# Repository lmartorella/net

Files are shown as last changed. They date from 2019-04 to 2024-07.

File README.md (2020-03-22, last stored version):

# Home

This is a hobbist/educational fulls stack project about Internet of Things (IoT) for DIY enthusiasts. It starts from scratch, using bare microcontrollers (MCU), network, and PC software without any relevant dependency.

The idea is about implementing a lost-cost open-source, open-hardware wired platform for general purpose automation control (for example domotic projects, security, garden automation, etc...). It is designed to connect a whole home and its surroundings.

The core of the project is a tiny MCU board that can embedded in any hardware, even a normal wall switch.

Node-to-node communication happens via common 4-wire or 6-wire low-voltage cables, like KNX, CAN-bus or other commercial systems, using industrial-grade [RS-485](https://en.wikipedia.org/wiki/RS-485) specifications for great scalability. Node-to-master communication is through IP (e.g. ethernet, wifi, etc...) for improved scalability. This allow wireless nodes to be implemented as well. 

What this project is aimed to:
- connect any type of sensor 
- integrate devices that can be interfaced via a MCU
- log data
- implement custom logic to automate tasks
- have a web interface for remote control

The bus structure allow extension with other open standards for IoT.

# The network

The network topology uses two mediums: a custom wired low-voltage bus to allow simple MCUs to be used, and a higher LAN/IP level to aggregate wired sections and server connection.

The wired design is similar to the [KNX](https://en.wikipedia.org/wiki/KNX_(standard)) open standard. However, instead of using proprietary electrical bus drivers, it relies on the broadly available [RS-485](https://en.wikipedia.org/wiki/RS-485) standard (for example, a [Maxim MAX485 IC](https://www.maximintegrated.com/en/products/interface/transceivers/MAX485.html) can be used as a driver).

An industrial-level RS-485 bus can range up to 32 nodes on the same wire and span hundreds of meters, even on electrically noisy environments. See [Maxim Integrated AN](https://www.maximintegrated.com/en/app-notes/index.mvp/id/3884).

Frames are byte-oriented, allowing a common bi-directional [UART](https://en.wikipedia.org/wiki/Universal_asynchronous_receiver-transmitter) to be used. This simplifies the selection of the hardware, since no bit-level CAN-bus or MODBUS logic is required. 

Each wired section needs to contain a *master* node, that allows IP connection to the server through Wi-Fi or Ethernet cables (it needs both UDP and TCP).

The custom protocol built on top is designed to offer features to ease the network installation:
- Auto-discovery for all connected nodes
- Zero-configuration: allow dynamic allocation of nodes via push-button and a PC application
- Fail-over due to bus failures, IP connection failures or node failures.

The byte-level message-based protocol is then shared between wired sections and to increase simplicity and issue analysis.

More details [in this page](doc/protocol.md).

# The microbean (µBean)

The prototyped hardware is a small board (just 30x28mm) built around a cost-effective [Microchip PIC16F1827 MCU](https://www.microchip.com/wwwproducts/en/PIC16F1827), a RS-485 level adapter and a voltage regulator. The board expose almost all MCU lines to the maker, allowing a great amount of free digital and analog I/O pins.

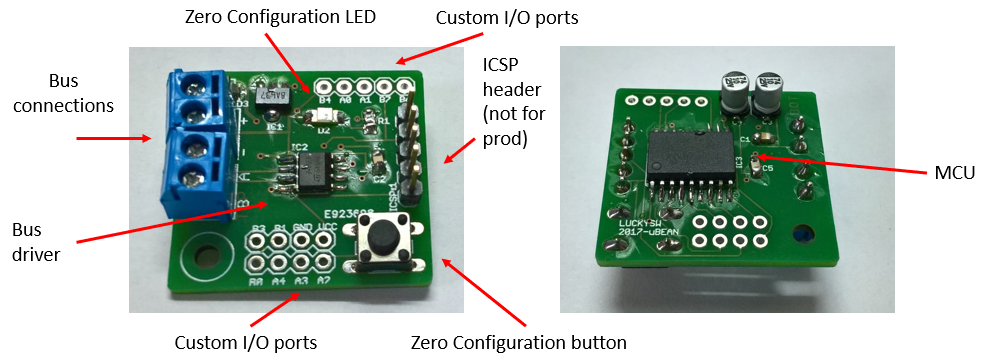
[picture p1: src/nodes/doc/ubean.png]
The microbean


Once the MCU are programmed, the network topology can be easily configured with a PC.

Each physical node exposes one or more applicative drivers, called *sinks*. In this way, a single bean can be programmed to interface more than one device.

More details can be found [here](./src/nodes/doc/microbean.md).

# Some examples

A collection of sample code for beans can be found in the samples folder.

Each sample is documented [here](./samples/beans/README.md).

## Light control

One bean installed in each wall box.
- Common switches will be used as low power digital switch drivers, or push button style
- Touch switches support
- RGB LEDs can be installed in each switch allowing soft tone transitions and night mode
- Power line relays or FET boards in separated junction boxes to control lights
- PWM with zero-cross detection dimmer boards for bulbs that support it
- IR motion/presence sensors support
- Luminance sensors for power saving support

## Intrusion detection and report

- A bean for each IR/motion sensor.
- A bean in junction boxes for window and doors magnetic switch.
- Beans at entrances for RFID or physical keys.
- Real-time notification of unusual activity
- Phone call/SMS/IM alert
- Remote control
- Remote activation/deactivation
- Smartphone control

## Climatization

Beans can be used to interact with existing climatization systems
- Temperature and humidity sensors
- IR emitters for fans and air conditioning units
- Actuator interfacing for motorized window shutters
- Regulation made based on weather forecast services

## Garden irrigation system

- Beans to control electrical valves
- Rain sensors
- Level meter for water tanks
- Relays board for submerged pumps
- Planning made based on weather forecast services

## Power management

- Interfacing with power meters that supports a serial port or a IP protocol.
- Interfacing with solar inverters.
- Wind meters to auto-close awnings.
- Connection with smart meters and devices.

# How to build

The project contains software elements (the .NET server, the node simulators and the control panel UI), hardware (the microbean) and the firmware for these nodes.

It is however possible to run the system with a software-only environment, using the node simulators to have a try.

## The server

The server code is a C# command-line process. It doesn't have any 3rd party dependency other than the .NET Framework, and it could be easily ported to [.NET Core](https://dotnet.microsoft.com/download).

However, currently it requires [Visual Studio](https://visualstudio.microsoft.com/) and [.NET Framework 4.x](https://dotnet.microsoft.com/download).

The project is splitted between the core part and the samples dlls, that are loaded automatically at startup via a plug-in load system, allowing modular architecture.

In addition, a WPF application is generated as a administrative interface (to visualize and set-up the network hierarchy) and to allow simulation of node logic and his sinks.

See [here](src/server/README.md) for more information.

## The master node

A master node is required to translate the IP connection from the server to the wired sections.

Custom hardware can be used there, but the simplest solution is perhaps to use an Arduino or a [Raspberry Pi Zero W](https://www.raspberrypi.org/products/raspberry-pi-zero-w/): something that can drive a bidirectional serial port and that can be connected to the LAN.

In this project you will found two implementations:
- for Raspberry (Raspbian) 
- for Microchip MCU with Ethernet support (e.g. PIC18F87). The [Microchip MPLAB X IDE](https://www.microchip.com/mplab/mplab-x-ide) with [XC8 compiler](https://www.microchip.com/mplab/compilers) is required in this case.

See [here](src/nodes/README.md) for more information.

## The wired node

You will find the schematics and the Microchip firmware to implement a wired node. Different ranges of MCU can be used, since the code and data requirements are quite limited.

The [Microchip MPLAB X IDE](https://www.microchip.com/mplab/mplab-x-ide) with [XC8 compiler](https://www.microchip.com/mplab/compilers) is required to compile the firmware and the samples.

See [here](src/nodes/README.md) for more information.

## The web server

A minimalistic web-server implementation is presented to allow remote access to the applications exposed by the server.

See [here](src/web/README.md) for more information.

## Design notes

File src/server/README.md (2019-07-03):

# The server: core C# projects

These are the projects that need to be built to implement the .NET server.

> The project doesn't have any 3rd party dependency other than the .NET Framework, in order to be ported to [.NET Core](https://dotnet.microsoft.com/download) or other platforms.

It requires [Visual Studio](https://visualstudio.microsoft.com/) (the free Community version is fine) and the [.NET Framework 4.x](https://dotnet.microsoft.com/download) for the administrative UI.

## Home.Common

This is C# library that shares code for the other two applications.

You will find here:
- Small dependency injection code
- Serialization services
- IPC services
- Logging a DB service
- The API to write applications: `IDevice` (the logic abstraction that needs one or more drivers) and `ISink`  (the driver part that communicates with the node over the Home protocol).
- An e-mail notification system.

## Home.Server

This is the command-line server process. It dynamically loads applicative *dlls* at startup (see samples) to integrate all the logic.

Place the sample dlls in the same folder of the main application: they will be recognized via attributes and loaded. 

## Home.Manager.UI

This WPF application can be used to:
- Visualize the network topology
- Initialize nodes
- Configure devices linking them to individual node sinks.
- Spawn simulated nodes on the IP network, for testing.

Like the server, also this application loads applicative dlls at startup. In addition to logic dlls, it allow UI dlls to load simulator and mock code as well.

## Application and samples

See [here](../../samples/server/README.md) for the samples, to build an application that does something.

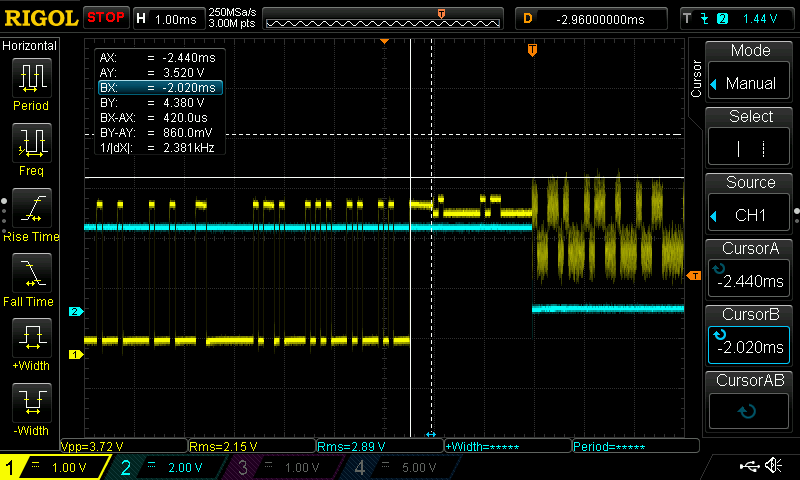
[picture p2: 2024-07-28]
doc/resp.png

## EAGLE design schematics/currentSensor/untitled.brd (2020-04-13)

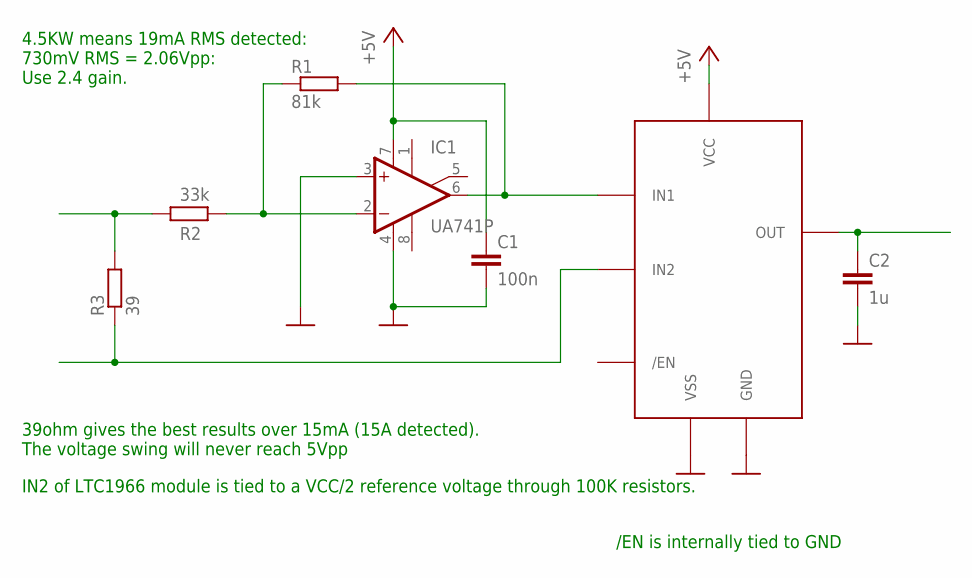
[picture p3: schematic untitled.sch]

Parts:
C1: 100n; C025-025X050
C2: 1u; C025-025X050
IC1: UA741P; DIL08
R1: 81k; 0207/10
R2: 33k; 0207/10
R3: 39; 0207/10
U$1: LTC1966_MODULE

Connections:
+5V: C1.1, IC1.7 (V+), U$1.P$1 (VCC)
GND: C1.2, C2.2, IC1.3 (+IN), IC1.4 (V-), U$1.P$2 (GND), U$1.P$3 (VSS)
unnamed: IC1.2 (-IN), R1.1, R2.2
unnamed: IC1.6 (OUT), R1.2, U$1.P$4 (IN1)
unnamed: R3.1, U$1.P$5 (IN2)
unnamed: R2.1, R3.2
unnamed: C2.1, U$1.P$6 (OUT)

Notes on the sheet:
IN2 of LTC1966 module is tied to a VCC/2 reference voltage through 100K resistors.
39ohm gives the best results over 15mA (15A detected). The voltage swing will never reach 5Vpp
/EN is internally tied to GND
4.5KW means 19mA RMS detected: 730mV RMS = 2.06Vpp: Use 2.4 gain.

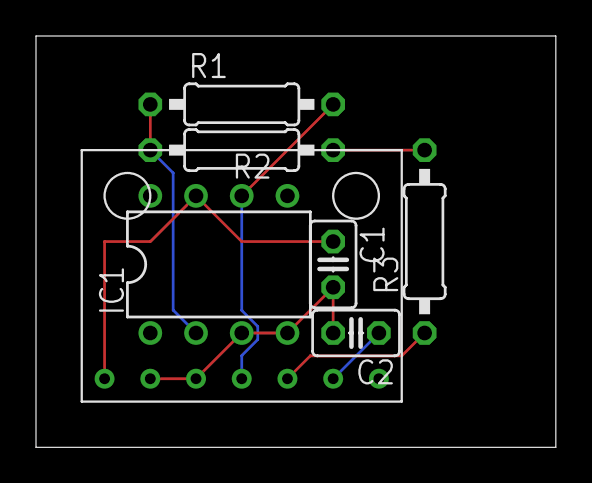
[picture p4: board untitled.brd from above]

Board: 2 copper layers, 28.9 x 22.9 mm, 7 parts (0 on the bottom side), 7 nets.

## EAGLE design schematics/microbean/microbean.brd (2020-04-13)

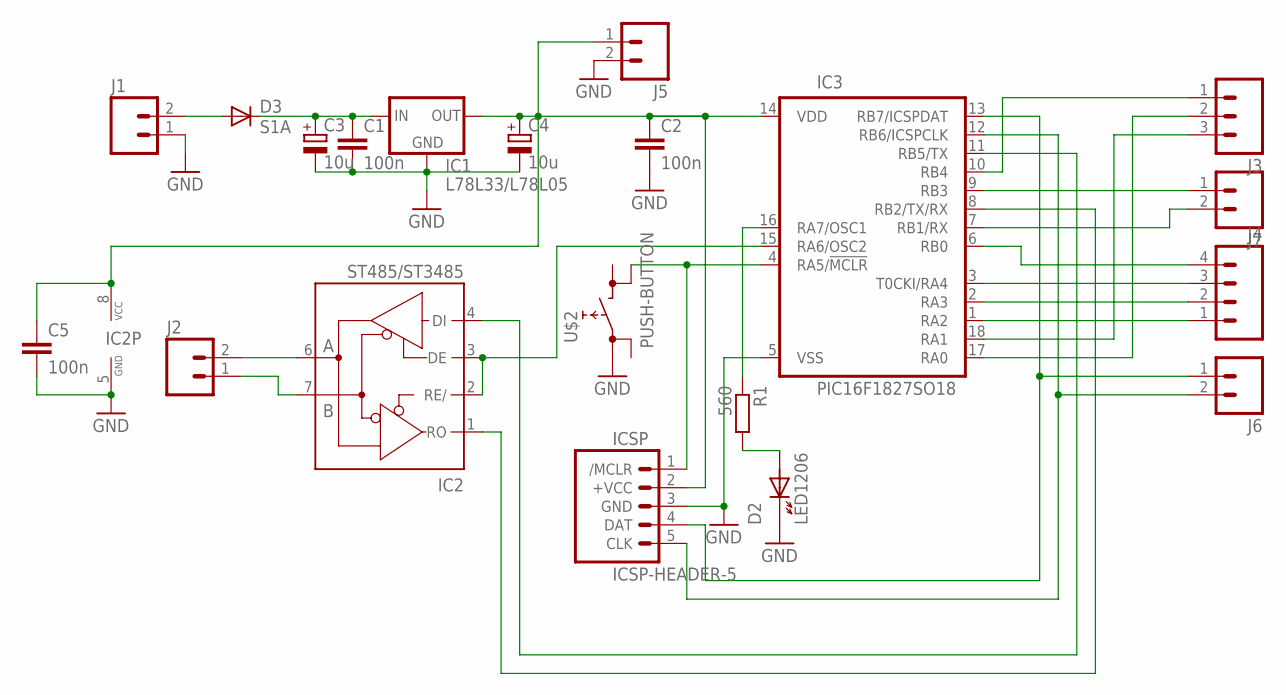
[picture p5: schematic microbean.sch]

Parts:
C1, C2, C5: 100n; C0805
C3, C4: 10u; UD-4X5,8_NICHICON
D2: LED1206; CHIPLED_1206
D3: S1A; SMA
IC1: L78L33/L78L05; SOT89
IC2: ST485/ST3485; SO08
IC3: PIC16F1827SO18; SO18W
ICSP: ICSP-HEADER-5; 1X05
J1, J2: M02-SCREW-3.5MM3.5MM; SCREWTERMINAL-3.5MM-2
J3: M03; 1X03
J4: M04; 1X04
J5, J6, J7: M02; 1X02
R1: 560; R0805
U$2: PUSH-BUTTON; MICRO-SWITCH

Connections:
A: IC2.6 (A), J2.2
B: IC2.7 (B), J2.1
GND: C1.2, C2.2, C3.-, C4.-, C5.2, D2.C (K), IC1.2 (GND), IC1.2@1 (GND), IC2.5 (GND), IC3.5 (VSS), ICSP.3 (GND), J1.1, J5.2, U$2.1 (0)
MCLR: IC3.4 (RA5/!MCLR), ICSP.1 (/MCLR), U$2.4 (1)
unnamed: D3.A, J1.2
unnamed: C1.1, C3.+, D3.C, IC1.3 (IN)
unnamed: D2.A, R1.2
RA0: IC3.17 (RA0), J3.2
RA1: IC3.18 (RA1), J3.3
RA2: IC3.1 (RA2), J4.1
RA3: IC3.2 (RA3), J4.2
RA4: IC3.3 (T0CKI/RA4), J4.3
RA6: IC2.2 (RE/), IC2.3 (DE), IC3.15 (RA6/OSC2)
RA7: IC3.16 (RA7/OSC1), R1.1
RB0: IC3.6 (RB0), J4.4
RB1: IC3.7 (RB1/RX), J7.2
RB2: IC2.1 (RO), IC3.8 (RB2/TX/RX)
RB3: IC3.9 (RB3), J7.1
RB4: IC3.10 (RB4), J3.1
RB5: IC2.4 (DI), IC3.11 (RB5/TX)
RB6: IC3.12 (RB6/ICSPCLK), ICSP.5 (CLK), J6.2
RB7: IC3.13 (RB7/ICSPDAT), ICSP.4 (DAT), J6.1
VCC: C2.1, C4.+, C5.1, IC1.1 (OUT), IC2.8 (VCC), IC3.14 (VDD), ICSP.2 (+VCC), J5.1

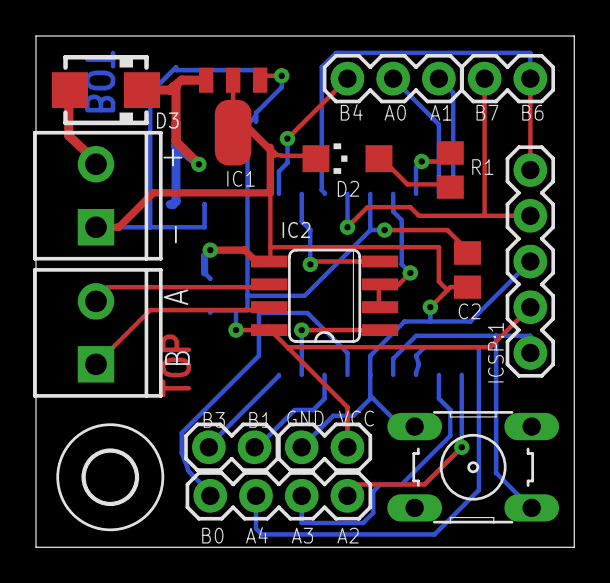
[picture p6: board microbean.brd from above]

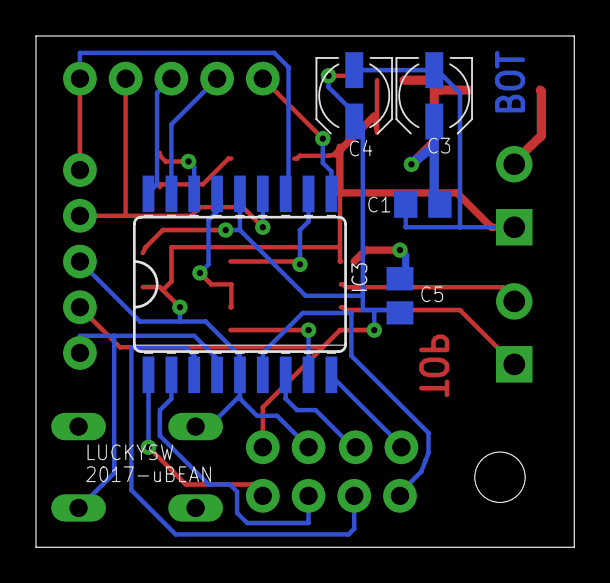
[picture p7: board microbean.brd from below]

Board: 2 copper layers, 29.9 x 28.4 mm, 21 parts (5 on the bottom side), 23 nets.

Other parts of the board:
U$4: 2,8

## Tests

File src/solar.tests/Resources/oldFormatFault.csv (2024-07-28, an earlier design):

TimeStamp | PowerW | TotalEnergyKWh | Mode | EnergyTodayWh | GridCurrentA | PanelCurrentA | GridVoltageV | PanelVoltageV | GridFrequencyHz | Fault
07:52:01 | 10 | 2529 | 0 | 0 | 0.00 | 0.00 | 226.4 | 106.7 | 50.00 | 0
07:52:16 | 20 | 2529 | 2 | 0 | 0.00 | 0.00 | 226.4 | 109.3 | 49.97 | 8192
07:52:31 | 30 | 2529 | 0 | 0 | 0.00 | 0.00 | 226.6 | 117.2 | 49.99 | 0

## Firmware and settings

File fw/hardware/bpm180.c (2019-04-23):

#include "../pch.h"
#include "bpm180.h"
#include "i2c.h"
#include "./appio.h"

// BPM180 I2C module to read barometric data (air pressure)
#ifdef HAS_BPM180

static TICK_TYPE s_lastTime;
#define REG_READ 0xef
#define REG_WRITE 0xee

#define MESSAGE_READ_TEMP 0x2e
#define MESSAGE_READ_PRESS_OSS_0 0x34
#define MESSAGE_READ_PRESS_OSS_1 0x74
#define MESSAGE_READ_PRESS_OSS_2 0xb4
#define MESSAGE_READ_PRESS_OSS_3 0xf4

#define ADDR_CALIB0 0xaa
#define ADDR_CALIB21 0xbf
#define ADDR_DEVICE_ID 0xd0
#define ADDR_MSG_CONTROL 0xf4
#define ADDR_MSB 0xf6
#define ADDR_LSB 0xf7
#define ADDR_XLSB 0xf8

// BPM180 state machine
static enum {
    STATE_IDLE,
    STATE_ASK_ID,
    STATE_RCV_ID,
    STATE_ASK_CALIB_TABLE,
    STATE_RCV_CALIB_TABLE,
    STATE_ASK_TEMP,
    STATE_ASK_TEMP_2,
    STATE_RCV_TEMP,
    STATE_ASK_PRESS,
    STATE_ASK_PRESS_2,
    STATE_RCV_PRESS
} s_state;

static BYTE s_buffer[16];
static int s_counter = 0;

static struct {
    short ac1;
    short ac2;
    short ac3;
    unsigned short ac4;
    unsigned short ac5;
    unsigned short ac6;
    short b1;
    short b2;
    short mb;
    short mc;
    short md;
} s_calibTable;
// Uncompensate temp
static unsigned long s_ut;
// Uncompensate pressure
static unsigned long s_up;

void bpm180_init() {
    s_state = STATE_IDLE;
    i2c_init();
    s_lastTime = TickGet();
}

void bpm180_poll() {
    int oss = 3;
    BOOL i2cIdle = i2c_poll();
    if (!i2cIdle) {
        return; 
    }
    
    switch (s_state) {
        case STATE_IDLE:
            // Start reading?
            if ((TickGet() - s_lastTime) > (TICK_SECOND * 2)) {
                s_buffer[0] = ADDR_DEVICE_ID;
                i2c_sendReceive7(REG_WRITE, 1, s_buffer);
                s_state = STATE_ASK_ID;
            }
            break;
        case STATE_ASK_ID:
            // Start read buffer
            i2c_sendReceive7(REG_READ, 1, s_buffer);
            s_state = STATE_RCV_ID;
            break;
        case STATE_RCV_ID:
            if (s_buffer[0] != 0x55) {
                fatal("B.ID");
            }

            // Ask table
            s_buffer[0] = ADDR_CALIB0;
            i2c_sendReceive7(REG_WRITE, 1, s_buffer);
            s_state = STATE_ASK_CALIB_TABLE;
            break;
            
        case STATE_ASK_CALIB_TABLE:
            // Start read table
            i2c_sendReceive7(REG_READ, 22, (void*)&s_calibTable);
            s_state = STATE_RCV_CALIB_TABLE;
            break;

        case STATE_RCV_CALIB_TABLE:   
            // Change endianness
            for (int i = 0; i < 11; i++) {
                BYTE b1 = ((BYTE*)&s_calibTable)[i * 2];
                ((BYTE*)&s_calibTable)[i * 2] = ((BYTE*)&s_calibTable)[i * 2 + 1];
                ((BYTE*)&s_calibTable)[i * 2 + 1] = b1;
            }
            
            // Ask temp
            s_buffer[0] = ADDR_MSG_CONTROL;
            s_buffer[1] = MESSAGE_READ_TEMP;
            i2c_sendReceive7(REG_WRITE, 2, s_buffer);
            s_state = STATE_ASK_TEMP;
            s_lastTime = TickGet();
            break;
        case STATE_ASK_TEMP:   
            if ((TickGet() - s_lastTime) > (TICKS_PER_MSECOND * 5)) {
                s_buffer[0] = ADDR_MSB;
                i2c_sendReceive7(REG_WRITE, 1, s_buffer);
                s_state = STATE_ASK_TEMP_2;
            }
            break;
        case STATE_ASK_TEMP_2:
            // Read results
            i2c_sendReceive7(REG_READ, 2, s_buffer);
            s_state = STATE_RCV_TEMP;
            break;
        case STATE_RCV_TEMP:
            // invert temp
            s_ut = ((unsigned long)s_buffer[0] << 8) | (unsigned long)s_buffer[1];

            // Ask pressure (min sampling)
            s_buffer[0] = ADDR_MSG_CONTROL;
            s_buffer[1] = MESSAGE_READ_PRESS_OSS_3;
            i2c_sendReceive7(REG_WRITE, 2, s_buffer);
            s_state = STATE_ASK_PRESS;
            s_lastTime = TickGet();
            break;
        case STATE_ASK_PRESS:   
            if ((TickGet() - s_lastTime) > (TICKS_PER_MSECOND * 30)) {
                s_buffer[0] = ADDR_MSB;
                i2c_sendReceive7(REG_WRITE, 1, s_buffer);
                s_state = STATE_ASK_PRESS_2;
            }
            break;
        case STATE_ASK_PRESS_2:
            // Read results
            i2c_sendReceive7(REG_READ, 3, s_buffer);
            s_state = STATE_RCV_PRESS;
            break;
        case STATE_RCV_PRESS:
            // invert temp
            s_up = (((unsigned long)s_buffer[0] << 16) | ((unsigned long)s_buffer[1] << 8) | (unsigned long)s_buffer[2]) >> (8 - oss);

            float temp, press;
            long b5;
            {
                // Calc true temp
                long x1 = (((long)s_ut - (long)s_calibTable.ac6) * (long)s_calibTable.ac5) >> 15;
                if (x1 == 0 && s_calibTable.md == 0) {
                    fatal("B.DIV");
                }
                long x2 = ((long)s_calibTable.mc << 11) / (x1 + s_calibTable.md);
                b5 = x1 + x2;
                short t = (b5 + 8) >> 4;  // Temp in 0.1C
                temp = t / 10.0;
            }
            {
                long b6 = b5 - 4000;
                long x1 = ((long)s_calibTable.b2 * ((b6 * b6) >> 12)) >> 11;
                long x2 = ((long)s_calibTable.ac2 * b6) >> 11;
                long x3 = x1 + x2;
                long b3 = ((((long)s_calibTable.ac1 * 4 + x3) << oss) + 2) >> 2;
                x1 = ((long)s_calibTable.ac3 * b6) >> 13;
                x2 = ((long)s_calibTable.b1 * ((b6 * b6) >> 12)) >> 16;
                x3 = ((x1 + x2) + 2) >> 2;
                unsigned long b4 = ((long)s_calibTable.ac4 * (unsigned long)(x3 + 32768)) >> 15;
                unsigned long b7 = ((unsigned long)(s_up - b3) * (50000ul >> oss));
                if (b4 == 0) {
                    fatal("B.DIV2");
                }
                long p;
                if (b7 < 0x80000000) {
                    p = (b7 << 1) / b4; 
                } else {
                    p = (b7 / b4) << 1;
                }
                x1 = (((p >> 8) * (p >> 8)) * 3038) >> 16;
                x2 = (p * -7357) >> 16;                
                p += (x1 + x2 + 3791) >> 4; // in Pascal
                press = p / 100.0; // in hPa
            }
            
            // FOR ETH MASTER MODULE ONLY
            sprintf(s_buffer, "%4.1f'C %6.1fhPa", temp, press);
            println(s_buffer);
                        
            // DONE!
            s_state = STATE_IDLE;
            s_lastTime = TickGet();
            break;
    }
}

#endif

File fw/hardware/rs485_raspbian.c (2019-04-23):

#include "../pch.h"
#include "rs485.h"

#include <stdlib.h>
#include <stdio.h>
#include <stdint.h>
#include <string.h>
#include <unistd.h>
#include <sys/types.h>
#include <sys/stat.h>
#include <fcntl.h>
#include <sys/mman.h>
#include <errno.h> 
#include <math.h>

typedef enum {
    UART_REG_DR = 0x00,
    UART_REG_RSRECR = 0x01,
    UART_REG_FR = 0x06,
    UART_REG_IBRD = 0x09,
    UART_REG_FBRD = 0x0a,
    UART_REG_LCRH = 0x0b,
    UART_REG_CR = 0x0c,
    //UART_REG_IFLS = 0x0d,
    //UART_REG_IMSC = 0x0e,
    //UART_REG_RIS = 0x0f,
    //UART_REG_MIS = 0x10,
    //UART_REG_ICR = 0x11,
    //UART_REG_DMACR = 0x12
} UART_REGS;

typedef enum {
    UART_REG_FR_TXFE = 0x80,
    UART_REG_FR_RXFF = 0x40,
    UART_REG_FR_TXFF = 0x20,
    UART_REG_FR_RXFE = 0x10,
    UART_REG_FR_BUSY = 0x08
} UART_REG_FR_BITS;

typedef enum {
    // Sticky parity
    UART_REG_LCRH_SPS = 0x80,
    UART_REG_LCRH_WLEN8 = 0x60,
    UART_REG_LCRH_FEN = 0x10,
    UART_REG_LCRH_EPS = 0x04,
    UART_REG_LCRH_PEN = 0x02,
            
    UART_REG_LCRH_SPS_1 = (UART_REG_LCRH_SPS | 0),
    UART_REG_LCRH_SPS_0 = (UART_REG_LCRH_SPS | UART_REG_LCRH_EPS)
} UART_REG_LCRH_BITS;

typedef enum {
    UART_REG_CR_RXE = 0x200,
    UART_REG_CR_TXE = 0x100,
    UART_REG_CR_UARTEN = 0x01
} UART_REG_CR_BITS;

typedef enum {
    UART_REG_RD_FE = 0x100,
    UART_REG_RD_PE = 0x200,
    UART_REG_RD_BE = 0x400,
    UART_REG_RD_OE = 0x800
} UART_REG_RD_BITS;

typedef enum {
    GPIO_MODE_INPUT = 0,
    GPIO_MODE_OUTPUT = 1
} GPIO_MODE;

typedef enum {
    GPIO_REG_GPFSEL0 = 0,
    GPIO_REG_GPSET0 = 7,
    GPIO_REG_GPCLR0 = 10
} GPIO_REGS;

typedef struct {
    void* vmap;
    uint32_t size;
    int fdMem;
    volatile uint32_t* ptr;
} Mmap;

static Mmap* mmap_create(uint32_t base, uint32_t len) {
    Mmap* ret = (Mmap*)malloc(sizeof(Mmap));
    uint32_t page_size = 0x4000;//getpagesize();
    
    // Round first byte to page boundary
    uint32_t addr0 = (base / page_size) * page_size;
    uint32_t offs = base - addr0;
    // Round last byte to page boundary
    uint32_t addr1 = ((base + len - 1) / page_size) * page_size;
    ret->size = (addr1 - addr0) + page_size;
 
    ret->fdMem = open("/dev/mem", O_RDWR | O_SYNC);
    if (ret->fdMem < 0) {
       fatal("Mem open");
    }
    char* mmap_vmap = mmap(NULL, ret->size, PROT_READ | PROT_WRITE | PROT_EXEC, MAP_SHARED | MAP_LOCKED, ret->fdMem, addr0);
    if (mmap_vmap == MAP_FAILED) { 
       fatal("Mem map");
    }
    ret->ptr = (uint32_t*)(mmap_vmap + offs);
    return ret;
}

static void mmap_destroy(Mmap* map) {
    if (munmap(map->vmap, map->size) != 0) {
       fatal("Mem unmap");
    }
    if (close(map->fdMem) != 0) {
       fatal("Mem close");
    }
    free(map);
}

static void mmap_wr(const Mmap* map, int regaddr, uint32_t value) {
    map->ptr[regaddr] = value;
}

static uint32_t mmap_rd(const Mmap* map, int regaddr) {
    return map->ptr[regaddr];
}

static void gpio_setMode(Mmap* map, unsigned gpio, GPIO_MODE mode)
{
   int reg = GPIO_REG_GPFSEL0 + (gpio / 10);
   int shift = (gpio % 10) * 3;
   mmap_wr(map, reg, (map->ptr[reg] & ~(7 << shift)) | (mode << shift));
}

static void gpio_write(Mmap* map, unsigned gpio, unsigned value)
{
    int bank = gpio >> 5;
    int bit = (1 << (gpio & 0x1F));
    if (!value) {
        mmap_wr(map, GPIO_REG_GPCLR0 + bank, bit);
    }
    else {
        mmap_wr(map, GPIO_REG_GPSET0 + bank, bit);
    }
}

static void uart_init(Mmap* map, int baud, uint32_t parity) {
    double fb = 48000000.0 / (16.0 * baud);
    uint32_t ibrd = (uint32_t)floor(fb);
    uint32_t fbrd = (uint32_t)(fmod(fb, 1.0) * 64);

    // 1. Disable UART
    mmap_wr(map, UART_REG_CR, 0);
    // 2. Wait for the end of transmission or reception of the current character
    while (mmap_rd(map, UART_REG_FR) & UART_REG_FR_BUSY);
    // 3. Flush the transmit FIFO by setting the FEN bit to 0 in the Line Control Register, UART_LCRH
    mmap_wr(map, UART_REG_LCRH, 0);
    // 4. Reprogram the Control Register, UART_LCR, writing xBRD registers and the LCRH at the end (strobe)
    mmap_wr(map, UART_REG_IBRD, ibrd);
    mmap_wr(map, UART_REG_FBRD, fbrd);
    mmap_wr(map, UART_REG_LCRH, UART_REG_LCRH_WLEN8 | UART_REG_LCRH_FEN | parity | UART_REG_LCRH_PEN);
    // 5. Enable the UART.
    mmap_wr(map, UART_REG_CR, UART_REG_CR_TXE | UART_REG_CR_RXE | UART_REG_CR_UARTEN);
}

#define US_PER_BYTE (1000000ul / BAUD * 11)
// time to wait before engaging the channel (after other station finished to transmit)
#define ENGAGE_CHANNEL_TIMEOUT (US_PER_BYTE * 1)  
// additional time to wait after channel engaged to start transmit
// Consider that the glitch produced engaging the channel can be observed as a FRAMEERR by other stations
// So use a long time here to avoid FERR to consume valid data
#define START_TRANSMIT_TIMEOUT (US_PER_BYTE * 3)
// time to wait before releasing the channel = 2 bytes,
// but let's wait an additional byte since USART is free when still transmitting the last byte.
#define DISENGAGE_CHANNEL_TIMEOUT (US_PER_BYTE * (2 + 1))

bit rs485_over;
bit rs485_close;
bit rs485_master;
bit rs485_lastRc9;
bit rs485_skipData;
RS485_STATE rs485_state;

void rs485_init() {
    
}

void rs485_poll() {
    
}

void rs485_write(BOOL address, const BYTE* data, BYTE size) {
    
}

bit rs485_read(BYTE* data, BYTE size) {
    return 0;
}

BYTE rs485_readAvail() {
    return 0;
}

BYTE rs485_writeAvail() {
    return 0;
}

void rs485_waitDisengageTime() {
}

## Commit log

2016-07-04 - WIP routing board MCU
2016-07-07 - Work done, MCU board finished
2016-07-13 - Finished MCU board
2016-07-29 - WIP 5V DIP bean
    [bean.sch]
2016-08-01 - Aborted, made with wireframe (solar)
2017-05-18 - WIP
    [microbean.brd, microbean.sch]
2019-04-21 - Implemented CM1602 LCD display driver as 8bit and 4bit IF
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2019-04-21 - working at preprocessor bug (concat)
    [fuses.h, main.c]
2019-04-21 - refactored utilities.h and macros - fix 23k256 module
    [fuses.h, main.c]
2019-04-21 - Testing 4-bit mode display features, searching for correct way to reset it
    [main.c]
2019-04-21 - Fixed display behavior after a SW RESET
    [main.c]
2019-04-21 - Still display issues with fatal errors at reset...
    [main.c]
2019-04-21 - Working at the bloody reset display issue
    [fuses.h, main.c]
2019-04-21 - Fixed Persistence issue, now the data is in their own ROM page
    [main.c]
2019-04-21 - Fixed SPIRAM module! - Optimized performances (XC8 free compiler)
    [spiram.c]
2019-04-21 - Fixed buffer SPI write/reads - Fixed and refactored display sink and its sink adapter in server - Fixed early TCP/IP socket closure - Reduced warnings
    [main.c, spiram.c]
2019-04-21 - MP3 tests passes - Changing SPI sampling timing for RAM too
2019-04-21 - Fixed sine test, audio bouncing from L to R
    [main.c]
2019-04-21 - Start writing audio sink (not tested yet), missing server-side backend
    [main.c]
2019-04-23 - Timers broken. Writing a test app, but stick with ltoa issue
    [main.c]
2019-04-23 - Issue with timers replicated!
2019-04-23 - Thinking that the glitch was due to cross-bound RAM writing, reduced the buffer size to 32Kb (first bank ONLY), but the glitch is still there - In parallel, demonstrated that the number generator w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
    [main.c, spiram.c]
2019-04-23 - Working MP3 speech on device. - Still glitches when the buffer is filling. Only uses 32Kb now.
    [main.c, spiram.c]
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2019-04-23 - Disabling fuses: display, spi, mp3, etc... (NOT TESTED) - Reinstalled MPLAB X
2019-04-23 - Fixed compilation problems - Reduced number of sockets to compile
2019-04-23 - Refactored protocol/ip division - Readded one UDP socket (needed for dhcp)
2019-04-23 - Fixed fw, worked around C compiler issue decoupling memcpy from ROM outside TCP routines - Fixed srv, don't close TCP client until bean consumed bytes (correct?) - Still some issues with multiple s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
2019-04-23 - Refactored namespace - Preparing structure for Devices (HAL of sinks)
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2019-04-23 - Finished: Better "rename" flow. TO test the whole stack
2019-04-23 - Working at switch Sink - Try to resume work on Devices
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2019-04-23 - WIP: multi sink devices - WIP: switch device
2019-04-23 - Fixed threading issue with TcpConnection
2019-04-23 - Added manual refresh in Admin UI - Some info in device list
2019-04-23 - Fixed device Persistence - Fixed device sink allocation at startup
2019-04-23 - Implemented device remove - Fixed startup glitch in switch device
2019-04-23 [REVERTED] - Fixed threading issue with TcpConnection - not compliant with multiple access to TcpConnection from different threads
2019-04-23 - Added ping code to test wiring against raspberry
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2019-04-23 - Fixed timer to wait for line free (min 1, max 2 ms) - Fixed demo code for MCU and bean
    [main.c]
2019-04-23 - Rewritten socket login in a better better way
2019-04-23 - Added timeout for bus socketed operations - Start debugging mcu card
2019-04-23 - Simplified timer management - Fixed RS485 timings - Fixed protocol, now scan on 5 seconds
    [fuses_mini_bean.h, main.c]
2019-04-23 - Separated timer code for pic16 (uses 16bit only) - Now minibean compile
2019-04-23 - Refactored exception management - Implemented reset reasons for PIC16F
    [fuses_mini_bean.h, main.c]
2019-04-23 - Fixed timer issues on PIC16 - Fixed protocol client
    [fuses_mini_bean.h]
2019-04-23 - Fixed bug on switching from RX to TX - Added timing constant - Changed timings, see OSI model doc
    [fuses_mini_bean.h]
2019-04-23 - Fixed issue with 1-to-0 channel read switch
2019-04-23 - Implemented push-button to register subnodes - Fixed a lot of issues in server C# - Testing with simpler version of memcmp (not used yet)
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2019-04-23 - DHT11 temperature/humidity sensor working. To stabilize readings.
    [fuses_mini_bean.h, main.c]
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2019-04-23 - Making "CLOS" command a sort of level-up command instead of socket destroy. - Added byte ack receive in order to have the possibility to free the bus and reused it for a new children without closin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
2019-04-23 - Switches for mini-bean, first test draft - Fixes
2019-04-23 - Added "NONE" to reset status, reset by server - Fixed bus socket loop in master node (caused by frame error) - Server still unstable with some zombie TCP connections
2019-04-23 - Disabled refresh button if refresh is in progress
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2019-04-23 - Trying to fix WM2002 display not working in MCU board
2019-04-23 - Fixed MCU board
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2019-04-23 - Minor fixes, now devices OK
2019-04-23 - Fixed the POR problem without PicKit (missing MCLR powerup res!) - Fixed reset reason display
2019-04-23 - Working at resuscitating the solar bean after an aftervoltage... - Fixed RS232 sw sending, still working to receive - Fixed MCU card to enable the bus power by default
    [main.c]
2019-04-23 - Fixer RS232 sw and tested with a local echo
    [main.c]
2019-04-23 - Added debug to RS232 for pic16 beans (solar HAS a rs232 port) - Fixed FERR state - Fixed subnodes connection drop in server
    [main.c]
2019-04-23 - Fixed everything. Found that the issue could be do the wrong management of frame errors, that was reported as error but invarianly present since TX/RX channel switch. Now trying to get rid of it, a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
    [main.c]
2019-04-23 - Fixed the sink, that shouldn't break the channel - Fixed exceptions in C#
    [main.c]
2019-04-23 - Fixed auto-adress without MCLR button - Changed the SYS SINK to allow RESET and other commands + GUI - Added info in master (number of registered nodes) - Fixed RS232 sampling - Removed conf for te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
2019-04-23 - Added DEBUG traces to understand issues in subnode CHIL responses
2019-04-23 - Added detailed error description in case of net buffer overflow (serializer)
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2019-04-23 - Refactoring eeprom write support, issues
    [main.c]
2019-04-23 - Fixed loop in persistence save - Fixed DHCP broken after GUID rename - Remade API and cache access of persistence
    [main.c]
2019-04-23 - Fixed some case of socket timeout in half/duplex (but not all) - Code cleaning - Fixed reset from Admin UI
2019-04-23 - Fixed issue of bus timeout -> not resetting the TCP socket -> the server sends subsequent commands to the master node instead of child nodes
2019-04-23 - Built eth tester for RS232 client issues
    [main.c]
2019-04-23 - Resolved reentrancy in interrupt code - Resolved tcp connection reused after socket closed because not sensing close from the MCU part
2019-04-23 - Added macro to disable bus stuff (for dcf77 clock tester) - Fixed DCF algo
    [main.c]
2019-04-23 - Fixed random WDT events in solar bean (runs without prescaler, used by TMR0 -> Tick)
    [main.c]
2019-04-23 - Working solar! - Fixed rs232 timeouts - socket timeout to 2sec.
2019-04-23 - Merging bus code into garden bean: - Raised clock from 1MHz to 4Mhz to allow RS485 correct baud and increased processing (changed TMR1 prescaler). This will perhaps have best UI refresh - Created h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
    [fuses_garden_bean.h]
2019-04-23 ' Trying to resolve persistent timeout error (2 sec) in reading from a powered down SAMIL...
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2019-04-23 - Making some progress: UDP ok, TCP recv OK but broken in sending ACK
    [fuses_raspbian.h]
2019-04-23 - Fixed raspberry TCP stack. Working!
    [fuses_raspbian.h]
2019-04-23 - Refactoring UART/RS485 split - Implemented UART for raspberry
2019-04-23 - Fixes to refactored RS485 module. Still some issues in RX on PIC device
    [main.c]
2019-04-23 - Studying missing PERR on raspi...
    [main.c]
2019-04-23 - FIXED UART!1!
2019-04-23 - Fixed remaining bits
    [fuses_raspbian.h]
2019-04-23 - Working but damn not working, in TX state the device gets reset
    [fuses_garden_bean.h, fuses_raspbian.h, main.c]
2019-04-23 - Added proper led and reset button to garden board - Removed temp EXC display - Added sink - Fixed serialization - Fixed running with PicKit attached (debug)
    [fuses_garden_bean.h, main.c]
2019-04-23 - Fixed high prio loop when socket is in use - Optimized UI loop, avoid division - Removed imm pers state
    [main.c]
2019-04-23 - Avoid abruptly reset whole microbeans and bus in case of temp disconnection of ETH in master (can cause solar error)
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2019-04-23 - Garden device supports immediate + r/garden to send it
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2019-04-23 - WIP pressure, wrong calcs
    [bpm180.c]
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2019-04-23 - Fixes: proper I2C reset at startup
    [bpm180.c, main.c]
2019-04-23 - Fixed linked project for raspberry
2019-04-23 - WIP for bmp10 sink on Eth tester board
2019-04-23 - Fixes (I2C not working on eth tester board with IP)
    [main.c]
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2019-04-23 Test: log E2E delays to understand why Raspberry master is lagging after some day
2019-04-23 Trying to avoid spinning timers in case of clog
2019-04-23 - Mega socket manager refactoring, avoid to have duplicated socket (MCU doesn't support that)
2019-04-23 - Trying to fix connection errors. - Fixed solar device that wasn't testing for sink liveneess
2019-04-23 - Fixed case of bounce that remains zombie
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2019-04-23 - Flow working! - Now TOFIX raspberry, not taking 2 sinks (clones the first sink in the metadata)
2019-04-23 - Added support for default device parameters (used for flow counter fq)
2019-04-23 - Added CSV logging for water flow in garden
2019-04-23 - Added flow and totals to garden CSV - Fixed issues
2019-04-23 - Fixed DIOR in mock UI and DIAR in SDK
    [fuses_micro_bean.h]
2019-04-23 - Fixed temperature sink mock - Fixed checksum calculation of DHT11 - Added mail in case of DB rotation error, now that is fixed
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2019-04-23 - Removed C# prototypes - Better folder structure
2019-04-24 Finished assembly rework of all projects
2019-04-27 WIP spit of mock UI in sample/core, and merge with admin ui
2019-05-01 base app working again TODO: Add all registered Sinks to UI tester TODO: simplify Admin/server API: no need to download devices, but use dll metadata TODO: Sink display name in topological tree
2019-05-11 - Refactored type managers and removed device type protocol between Admin and Server
2019-05-16 - Refactoring the web server - Added default garden cfg writer - Moved samples and webapp outside web code - Code simplification - Moved plotly and require to npm - Converted server code back to JS
2019-07-03 - Fixed garden sample build - Removed main bean project (in samples now) - Moved netmaster in samples
    [fuses_garden_bean.h, fuses_raspbian.h, main.c]
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2019-07-03 - Fixed NetBeans project for Raspbian
    [fuses_raspbian.h]
2019-11-03 - Renamed project for micro-bean - Fixed samples/sdk separation for sinks
    [fuses_micro_bean.h, main.c]
2020-03-22 - Removed support for external trigger - Added support for global Power relais for better power management
2020-03-23 - Added digital input simulator and tester device
2020-03-23 - Fixed logger device - Added Initialized async task in Sinks
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2020-03-24 - Fixed raspberry netmaster build
2020-03-24 - Implemented simulator too - Temp: update flow on web request
2020-03-25 - Fixed digio hw and c# sink driver
    [fuses_micro_bean.h, main.c]
2020-03-26 - Added debounce to digital input, at 0.1s (for normal switches and relais)
2020-03-29 - Fixed management of bean MCLR for idx update - Added persistence log for raspberry - Fixed server exception in case of stream dispose
    [fuses_raspbian.h]
2020-04-04 - Added statistics log in raspberry master nodes to analyze disconnection loop - Fixed TCP management in server to avoid loop of connections and disconnections, and refactor code to improve readabili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
2020-04-04 - Added pump logger - Refactored the big Garden device file in sub classes
2020-04-07 - Protocol webserver/server reworked - .NET message separation samples/core
2020-04-07 - Better mail report (text) - Added Night Mode switch in the simulator - Added protocol debug
2020-04-13 Merged bean-dip
    [bean.sch]
2020-04-13 - Aligned top symbols
    [board_disp.brd, board_power.brd]
2020-04-13 - Fixed missing wire VDD
    [board_power.brd, board_power.sch]
2020-04-13 - refoldered
    [microbean.brd, microbean.sch]
2020-04-13 - Refolder
    [bean.sch, mcu_board.brd, mcu_board.sch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]
2020-04-13 - WIP microbean for professional printing
    [microbean.brd, microbean.sch]
2020-04-13 - WIP, DRU finished
    [microbean.brd, microbean.sch]
2020-04-13 - Refinements
    [microbean.brd, microbean.sch]
2020-04-13 - Finishing up for quoting
    [microbean.brd, microbean.sch]
2020-04-13 - Ready for printing, optimized
    [microbean.brd, microbean.sch]
2020-04-13 - Fixed via size to comply with drill level A
    [microbean.brd]
2020-04-13 - Raspberry extension
    [untitled.sch]
2020-04-13 - Done wirewrap of raspberry extension!
    [untitled.brd, untitled.sch]
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2020-04-13 Current sensor
    [untitled.sch]
2020-04-13 - Sensor board
    [untitled.brd, untitled.sch]
2020-04-13 - Fixed solar TCP open/close loop - Added logs to listen socket issue on raspbian (missing POLLINVALID check?)
2020-04-19 - Readded proto board settings - Fixed new project upgrade
2020-04-26 - Integrated power usage reading in solar power to calculate Net Energy Meter
2020-05-03 - Found issue in waiting the PL011 raspberrys to be clear sometimes
2020-05-07 - Fixed messy children registration in case of populated node startup
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2020-05-08 - Fixed raspberry loop due to stale TCP connection: now keep-alive is set - Fixed issue in unzombie
2020-05-10 - Fixed deserialization buffer underflow management: TCP connection must be closed in that case to allow subsequent node access
2020-05-10 - Fixed reset reason in microBean: software exception was reported as MCrl, causing zero-configuration address assignment - Using real pointers instead of BYTE used for older PIC models
    [fuses_micro_bean.h]
2020-05-10 - Added a way to immediately re-fetch status in case of sub-node errors
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2020-05-13 - Optimized check in case of node error notification - Added tester code to raise exception at timer
    [fuses_micro_bean.h]
2020-05-13 - Fixed exception text in microbean
    [fuses_micro_bean.h, fuses_raspbian.h]
2020-05-13 - Upgraded HTBT message with child list - Simplified heartbeat management in case of zombie child or new child
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2022-10-31 - Fixed poll on posix
    [fuses_raspbian.h, main.c]
2022-11-05 - Fixed build on eth card
    [main.c]
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2023-05-29 - Fixed support for disconnected flow sensor
2023-09-02 - Scanner working. - TODO TX pin timing on end-of-write
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2023-09-10 - Moved
    [untitled.brd, untitled.sch]
2024-04-01 - Removing old net-related code
    [bean.sch, board_disp.brd, board_disp.sch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]
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2024-06-11 - Fixed error message in case of timeout
2024-06-17 - Fixed assembly name and target
2024-06-17 - Fixed assembly name
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2024-07-21 - MQTT debug level with --debug true switch
2024-07-24 - Merged folders
    [untitled.brd, untitled.sch]
2024-07-27 - Remerged ui libs and C# src
    [oldFormatFault.csv, oldFormatNoFault.csv]
2024-07-27 - Moved solar C# srcs
    [oldFormatFault.csv, oldFormatNoFault.csv]
2024-07-27 - Merged current sensor support in solar server
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2024-07-27 - Removed calibration, to move to a separate branch
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2024-07-28 - Added exported current measurement to CSV, to run analysis and do calibration
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
